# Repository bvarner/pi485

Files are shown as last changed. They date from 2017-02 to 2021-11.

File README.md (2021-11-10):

# Pi485 - UART TTL (Raspberry Pi / Arduino) to RS485
## What is it?
Pi485 lets you connect the RX / TX pins on your Raspberry Pi (/dev/ttyAMA0) or Arduino device to an RS-485 network, 
and transmit / receive as if the network were a normal serial device.

## What can it do?
* Create a low-cost RS-485 network of devices using serial I/O.
* Communicate with other RS-485 networks.

Recent models of HVAC equipment (so called, "communicating" units) typically use RS-485 for the physical connection.
This makes deciphering the comms stream a software problem, and one that many people have already started working on!

## Features
All of the project variations in this repository feature the following:

* Termination Jumper. None of the commercial offerings or existing modules I've seen allow you to disable the termination resistor. On a 
multi-module RS-485 network, it's necessary that middle-nodes not have the termination resistor in the circuit, or the bus signals will 
deteriorate significantly.
* Hardware Latched DE / RE pins on the MAX485 driven by TX activity, with a 'RO' (Read Only) jumper header.
Adding a jumper will force your device to be 'read only' by disabling the hardware latch of the DE / RE Pins.
* Software controlable off / on. Using a GPIO pin (3.3v) you can turn the circuit 'on' or 'off', allowing for a software reset of the 485 
module, pseudo "power management", or simply give you the time to setup your UART tty before initiating a communication connection.
If you prefer the 'always on' approach, you can simply hook up positive voltage to the control pin, and the circuit will always be on.

## What's in this repository?
This repository contains [KiCad EDA](http://kicad.org/) source schematics, PCB layouts, and rendered SVG plots.

The SVG Plots can be used to print your own PCB, or you could try using them as a template for making your own.

## What? Make my own PCB?
I've had good success with the layouts in this repo using the laser-printer hot-iron transfer method. I've gotten excellent results with 
Hammermill Color Laser Gloss (sku 163110) paper. It's a 32lb very smooth gloss paper like you'll find on lightweight magazine covers.
The 163110 takes and transfers toner very well, and is light enough for use in nearly every laser printer I've run across.
When soaked in water for a few minutes after ironing the paper easily peels off without removing the toner. I normally lightly sand the 
left-over transfer with 1500 grit paper to remove the last of the paper fibers and any gloss 'bleed' before chemical etching the board.

Now that I have my method down I could probably tweak the layouts to shrink the trace size (from 1.0 to 0.8 or 0.7) which would help with
some of the 'bleed' I sometimes get when doing the iron transfer.

I also have invested in some inexpensive carbide drill bit sets from 0.3 - 1.2mm for drilling the PCBs in a drill press.

If you're interested in a prebuilt board, contact me (bvarner) via github. I would be willing to coordinate a small run, and I may have a 
few boards on hand (or on ebay) you could convince me to part with.

## Usage
To setup a RaspberryPi so that you can use the UART for what you want rather than it exposing a serial console.

1. Use `raspi-config` to disable the serial console.
2. Enable the UART at boot by editing `/boot/config.txt` and setting `enable_uart=1`.
3. A pi485 requires a logic 'high' signal on the PWR (P1 connector, pin 5) signal line. You can wire up a +3.3v line to force power to always
be 'on', or you can control it with a GPIO pin.

If using a GPIO pin, a convenient way to manage this is to install `wiringpi`, and edit the `/etc/rc.local` script to add the following lines:
```
/usr/bin/gpio mode 1 out
/usr/bin/gpio write 1 1
```

You can also take the opportunity to set your tty settings in `/etc/rc.local` if you so desire.

## Hardware Configurations

### Standalone
This complete solution can be assembled from discrete components. It uses a Max485 IC, and NE555 timer, and some discrete components to 
implement a hardware level RS-485 interface that automatically controls the DE / RE pins based on TX activity, allows for jumper 
configuration of termination, and adds blinken-lights for TX / RX, and Power.

This configuration is the easiest one to fabricate at home. Everything from pad size, to trace width and clearance restrictions have been
tweaked to make this easier to work with for novices. Armed with a single-sided copper clad board, some ferric chloride, a fine-tipped 
sharpie marker and a steady hand, you could build this layout without doing an iron transfer. However, the component cost is higher. The
PDIP Max485 in small quantities is by itself more expensive than a single LC Technologies RS485 module used by the bearer configuration.

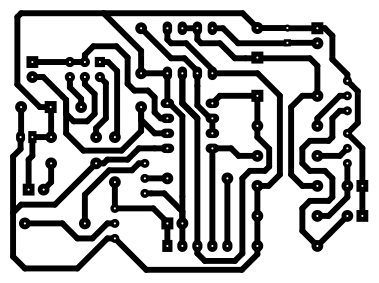
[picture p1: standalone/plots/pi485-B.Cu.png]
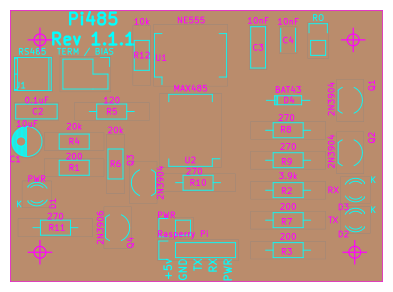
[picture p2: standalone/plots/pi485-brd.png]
 

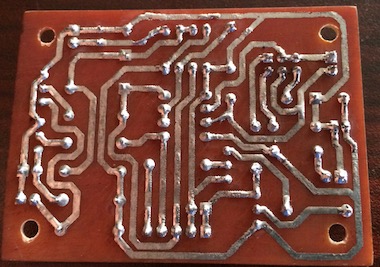
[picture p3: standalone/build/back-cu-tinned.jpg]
Tinned PCB
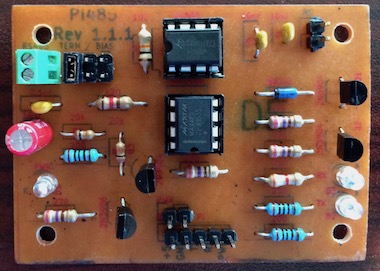
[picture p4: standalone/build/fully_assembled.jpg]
Assembled PCB
 

### Bearer
The bearer board is designed to hold an [LC Tech MAX485 module](http://www.chinalctech.com/index.php?_m=mod_product&_a=view&p_id=811), which
is an inexpensive module based around a max485 in a surface-mount, slew-rate limited configuration. 
These modules include some support components like power filtering capacitors, a power LED, and some pull-up resistors.
Building a bearer board is a bit more tricky, as it has lower clearance tolerances between traces, thinner traces, and requires that you 
modify (unsolder) some resistors off the LC Tech module. However, when full BOM part costs are taken into consideration, if you're making
more than one pi485, it'll be cheaper to use the bearer configuration.

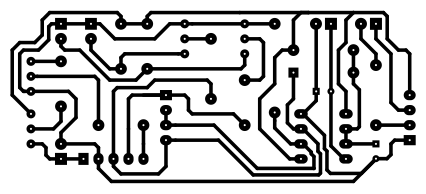
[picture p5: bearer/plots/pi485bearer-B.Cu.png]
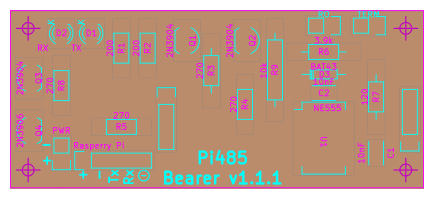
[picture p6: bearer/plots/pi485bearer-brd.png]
 

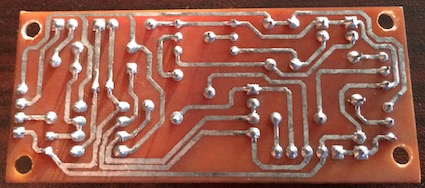
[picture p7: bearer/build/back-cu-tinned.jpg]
Tinned PCB
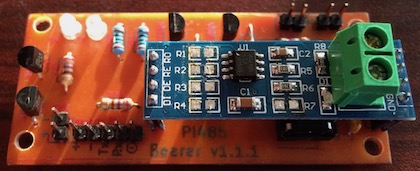
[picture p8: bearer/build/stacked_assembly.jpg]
 

The bearer board adds the 555 latch circuit for DE/RE control from the TX line, RX / TX LEDS, power on/off, and 
jumper termination control from the standalone board design (if you unsolder the 120Ohm resistor on the LC Tech module).

In my experience, if you want to make more than one of these devices, it's much cheaper to purchase the LC Tech modules and build Pi485 
bearer boards to hold them.

## Project Background
I've had a couple Raspberry Pi's laying about my home for a few years now. After running across the 
[Infinitude project](https://github.com/nebulous/infinitude), I realized that my 
HVAC system (a Bryant unit) is actually a 'communicating' system as well. I've had in the back of my mind for some time a project to hook up
a raspberry pi, and track long-term time-series data on my HVAC unit, performance, and temperature differentials.

### Off The Shelf Module Shortcomings / Circuit Analysis / Reasons this project exists.

Almost every module I've looked at is based on the [MAX485](http://datasheets.maximintegrated.com/en/ds/MAX1487-MAX491.pdf).

#### Overly simplistic opinionated view of RS-485.
It seems that off-the-shelf modules tend to approach the MAX485 series of half-duplex (two wire RS485) chips as a pretty simple TTL->485 
converter, suitable for locating at the _endpoints_ of a very simplistic single master-slave network. In order to drop in multiple modules 
(multiple slaves) or enable multi-master communications and form a true network, there's some hardware work that needs to be done (removing
termination resistors) and software control of the RE / DE with a GPIO (which open you up to a whole slew of software timing issues).

#### Soldered on Termination
For example, the LinkSprite module and the LC Tech modules both carry 120Ohm termination resistors, and no jumper header to remove it from
the circuit. The only practical option to add these modules as a network node other than an 'end point' is to unsolder that resistor.

#### Lack of TX / RX Visibility
I like [blinkenlights](https://en.wikipedia.org/wiki/Blinkenlights). These products should have blinkenlights.

#### DE / RE Pin Hysteresis 
Additionally, the LC Tech module has the DE and RE pins of the Max485 directly accessible over headers but provides no extra circuitry to 
drive the input to those pins based off the TTL TX. These two pins of a Max485 are responsible for setting the duplex state of the chip 
(Driver Enable / Receiver Enable) for either sending or receiving data. The RE pin is active on Logic Low (GND) and the DE pin is active on 
Logic High (~20ma of forward voltage). For this reason, you'll commonly see these pins wired together. When set High, the Max485 disables
receiving, and enables transmitting. When pulled low, it enables receiving and disables transmitting. The LC Tech module seems to defy all 
logic and reason in how it wires up the DI, DE, RE, and RO pins. Each pin has a 10k pull-up resistor. So unless you're actively draining 
these pins to ground with your logic circuits,  your max485 is going to end up in "write" mode by _default_. In a multi-master half-duplex
system like an HVAC unit (the initial target application for pi485) this causes a big problem.

I've found many schematics which suggest tying the DE / RE pins to a separate GPIO. This is a terrible idea in practice. In a busy RS485 bus
the time between the DI/DE pins shifting and the start of output on the TX pin would effectively guarantee a collision on the network.

I've also found schematics for RS-232 -> RS-485 converters which work by converting the 232 signal to TTL, then the TTL to RS-485. In these
circuits, they tend to leverage a 555 timer as a time-delayed latch, to hold the DE / RE pins in transmit mode based on the state of the TTL
TX pin. This seems like a really good idea in theory, and in circuit simulations (I don't have a physical scope) it appears that the 555
output will respond quickly enough for at least a 38400baud network to cleanly communicate all the necessary symbols over the wire (given 
the sizing of resistors and capacitors in use with the 555).

In this [555 TTL Latch Simulation](http://tinyurl.com/hx6gfwh), there's a +5V supply, GND, and a H/L logic input (clickable) on the left. 
The output pin of the 555 has a H/L output detector on it, and drives an NPN transistor to turn on an LED. In a real circuit using this 
technique, the 555 output pin would drive the DE/RE pins on a Max485. As an example, checkout the 
[AVT530](http://serwis.avt.pl/manuals/AVT530.pdf), an RS232 to RS485 converter that uses TTL as an intermediary. The schematic is on page 2.

The same company also uses this same 555 & Max485 circuit on their [USB to RS485](http://serwis.avt.pl/manuals/AVT530USB.pdf) converter.

The down-side with these circuits, is that there is a timing differential after the TX pin stops transmitting that the RE pin is held high.
Recall earlier I mentioned things about start / stop bits? This is where that comes into play.
At 38400Hz (as in the simulation above) this delay accounts for an entire clock cycle of bit transmission on the bus. In the interactive 
simulations above, note how if you switch the TTL input high (0 or idle) it takes 2 clocks before the 555 sets the output back low. If your
bit protocol doesn't include a stop bit (idle / high) then the DE / RE will not be disabled at the appropriate time. Without stop bits, you 
will transmit one extra idle (logical 1) on the 485 bus and miss receiving a bit for a clock with these latched circuits.

Here's another [simulation of the 555 latch circuit with pulsed input](http://tinyurl.com/hn6zreu). In this revision, we've added a pull-up
resistor (5k) to the input trigger to hold it 'high' when idle, moved the input clk to drive a decade counter, and tied output pins from the
counter to switch an NPN transistor that sinks the trigger pin low when the counter has a high output. Think of the counter as sending 
logical 1's and 0's by pushing a switch. When the switch (transistor) is closed, the TR voltage drops to ground. If you have start or stop
bits enabled in your stream, this initial drop (0) will be the start bit, which will trigger the 555 output high. In the AVT circuits, this 
drives the RE / DE pins high, putting the MAX485 into transmit mode. An idle 'high' stop bit (Q8) will let the timer's capacitor drain, 
resetting it's output pin. But if you're not using start / stop bits... and you're just getting a stream of bits that is synchronized 
in software, then using a 555 latch is going to be asking for trouble.

In looking at the LinkSprite module, I found it interesting that it dispenses with a time-delay latch and supplies power to the DE / RE pins
via MOSFETS switching a 0.33mA current based upon the TX input. This seems rather 'icky' to me, since logically I would think the DE / RE
pins going 'high' whenever the TTL signal goes idle, would cause an issue. So I threw together a 
[simulation of the TTL input with MOSFET](http://tinyurl.com/glnvxa2) triggers. This confirmed what I thought as far as behavior without 
delay. The good news here, is if you're sending a '0' on the RS-485 bus, you'll transmit that 0, and be prepared to receive any values from
the bus immediately afterward. So if your protocol doesn't use stop bits, you'll be able to read the stream without error. The natural
question at this point is, "what if I'm trying to transmit a '1' (logical TTL high / idle value)?" In that case, the DE pin would be pulled
low, along with the RE pin, putting the MAX485 into Driver disable, Receiver Enabled mode. I'm not sure if this would effectively pulse the
RS-485 bus in an appropriate manner. The Bus signals bits based on bias differences between the two wires, A and B. Something about this
arrangement smells funny.

According to the stuff I've read on RS-485, a driver 'idle' would be A+, B- potentials. After pouring over the Max485 datasheet, I don't see
anything that will lead me to believe RE high / DE low would result in A+, B- potentials being emitted on output lines of the chip.

Nevertheless, it must work... right? Unless the LinkSprite and LC Tech components aren't being tested in multi-master half-duplex 
networks. I have a feeling that's exactly what's going on, since they both carry soldered-on termination resistors that cannot be 
jumper-disabled. That means that if you introduced a network of these devices with more than two nodes, you'd have pretty significant signal
degradation.

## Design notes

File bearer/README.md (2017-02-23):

# Pi485 Bearer Module

Based upon what I learned while creating the Standalone pi485, this board is meant to function as a carrier / bearer for an
[LC Technologies RS485 module](http://www.chinalctech.com/index.php?_m=mod_product&_a=view&p_id=811), adding the RX / TX LEDs,
power controll, and latched DE / RE pin driving to this very inexpensive and commonly available module.

Unlike the standalone board this layout prioritizes compactness over ease of use for beginners.
The trace clearances are tighter and you'll need to remove five surface mount resistors from the RS485 module. In practice, I've found 
these boards are reasonably easy to produce with a laser printer hot iron transfer.

## PCB Layout

Copper Layer Front Layers
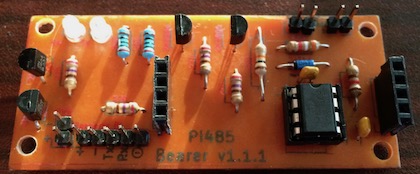
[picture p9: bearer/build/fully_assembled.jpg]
Assembled
Tinned PCB 

is designed to hold these RS485 modules

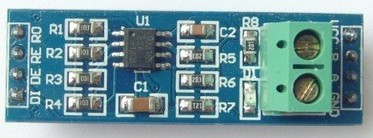
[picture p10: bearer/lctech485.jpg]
LCTech485
 Full Stack

## Schematic
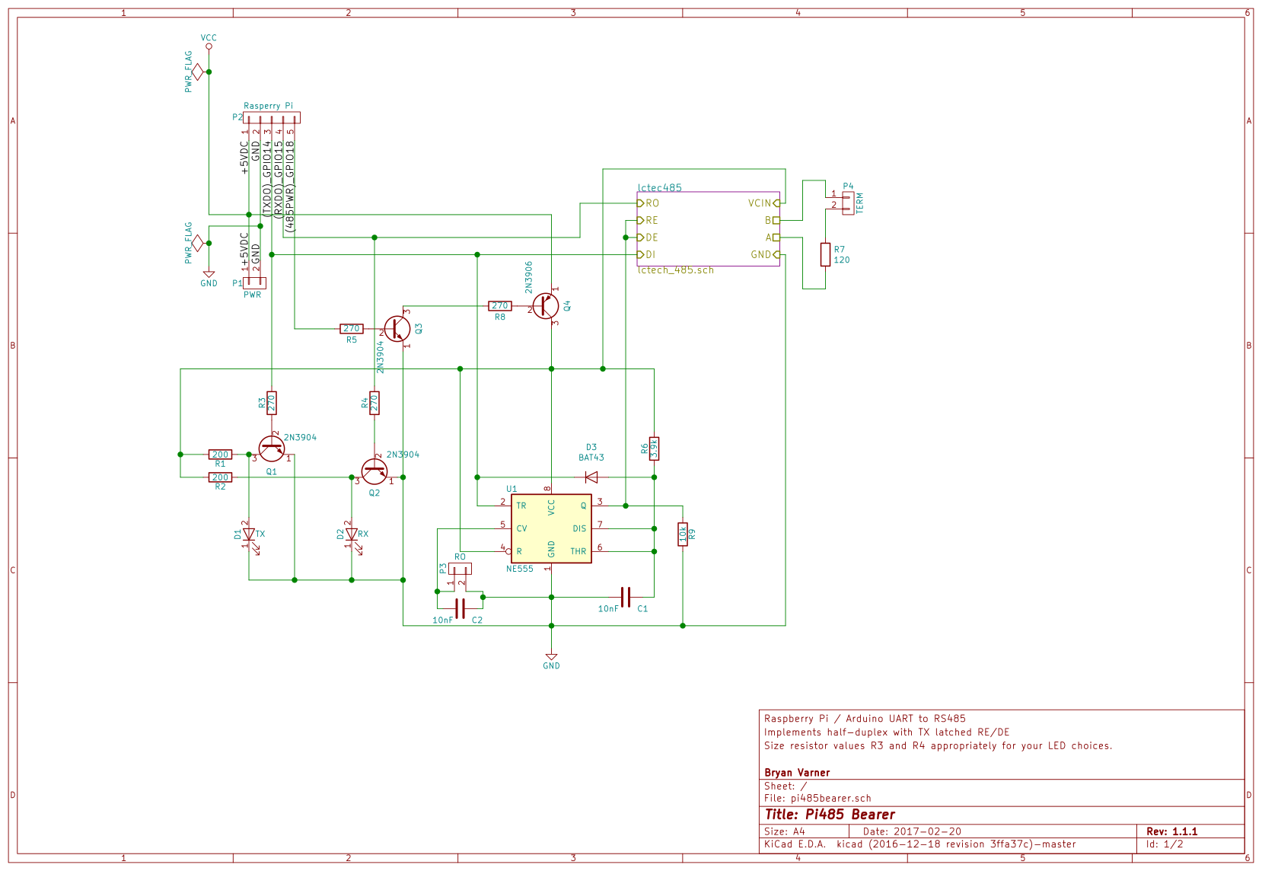
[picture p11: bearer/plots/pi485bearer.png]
Schematic


# Design Goals
* Add the functions and features of the standalone module in a slightly more compact layout that can accomodate inexpensive 485 modules.
* Leverage the RS 485 module due to the module cost being less than the the cost of a discrete terminal block header, max485 IC, power LED, 
LED resistor, and filtering capacitors. These boards do shave a couple USD off the cost of UART based RS-485.
* Latch the DE / RE pins on the Max485 based upon the UART TX activity, but allow that to be disabled (force read-only mode)
* Include jumper termination for the A/B lines of the RS485 bus.

For in-depth details on the function of [the circuit](plots/pi485bearer.png) refer to the [Standalone Module README](../standalone/README.md).

# Build Instructions

1. Start off by customizing the resistor values for your LEDs. I used [http://ledcalc.com/] to help inspire my choices.
2. Use KiCad's PCB editor (pcbnew) to customize any footprint changes.
3. Print the [back copper](plots/pi485bearer-B.Cu.svg) layer on a laser printer, using glossy photo paper.
4. Print the [front](plots/pi485bearer-brd.svg) layers on a laser printer, using glossy photo paper.
5. Cut your board (62mm x 30mm)
6. Transfer the copper printout using a hot iron and some water.... (youtube reference coming). Touchup with a resist pen if necessary.
7. Etch the board.
8. Clean the board.
9. Tin the board.
10. Reflow the board (bake it in an oven).
11. Drill the component holes.
12. Place & solder components.
13. Assemble!
14. Remove the 120Ohm resistor (R7), and the 4 10kOhm pull-up resistors (R1 - R4) from the LC Tech 485 Module.
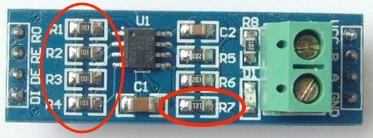
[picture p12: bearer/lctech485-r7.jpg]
R7 Has to Go


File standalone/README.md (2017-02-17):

# Pi485 Standalone Module

This is a stand-alone module for RS-485 communication, utilizing a MAX485 IC and a NE555 Timer IC.
The PCB for this project is the most 'simple' of the two to etch yourself. Most of the pads are 
oversized, the copper traces are significantly wider and spaced far enough that it's possible 
to create a PCB with a resist marker by hand. 

## PCB Layout
Copper Layer Front Layers

## Assembled
Back Cu Tinned Populated

## Schematic
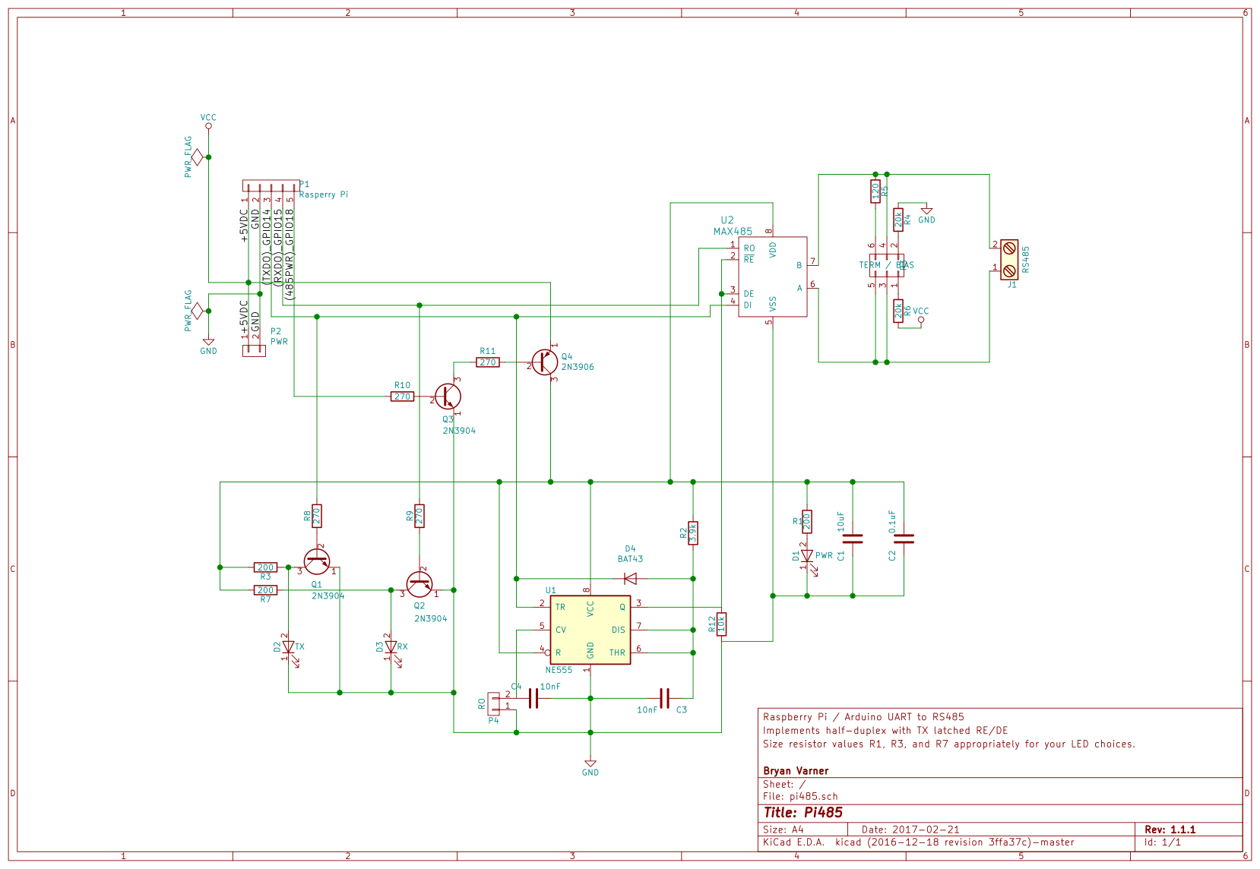
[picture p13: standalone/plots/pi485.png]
Schematic


# Design Goals
* [Simple / Easy To Understand Circuit](plots/pi485.png)
* Easily fabricated at home with simple tooling
* Reasonably inexpensive to source parts for and build (~$20 or less)
* Latch the DE / RE pins on the Max485 based upon the UART TX activity, but allow that to be disabled (force read-only mode)
* Include jumper termination for the A/B lines of the RS485 bus.

To achieve these goals the PCB layout in this repository is a single-side clad board, components on the front, copper on the back.
The traces are large (0.4mm!), the pads are oversized where possible, and I've allowed plenty of clearance between traces and pads, making
it possible to touch-up a hot-iron transfer with an ink-resist pen. You may even be able to draw the existing tracks with a pen free-hand.

For tooling, you'll need the 'standard' PCB etching supplies; a bottle of Ferric Chloride, some isopropyl alcohol, gloves, 
a dish to do the etching, and an appropriately sized drill bit. (I had a 0.040" bit in a set) I'd recommend you have a drill press, too.

I highly recommend doing a hot-iron transfer of laser printer toner. Print the SVGs using a laser printer onto glossy photo (or magazine)
paper. Heat the board with an iron, then stick the printout to the board. Press the printout firmly to the board using the hot iron (you're
goal is to melt the toner to the board surface), and then start soaking with water and continue steaming. Firm pressure and heat will do a
good job of sticking the printout onto the board. It works surprisingly well. Once you've steamed the paper (or soaked it in water) and it
starts to fall of the board, you can touchup any trace or pad issues with a resist pen, and etch the board.

I also use a kitchen oven to bake the board once it's tinned. Getting it up to ~425 degrees F does a nice job of reflowing the solder,
which makes it much easier to drill the holes.

# Circuit Analysis / Explanation

## TTL Serial Communication Basics
TTL signaling of serial data idles 'high'. When data is being transmitted on the TX pin, it first drops 'low' (a start bit), 
transmits it's data, and then sends a stop bit. In TTL, a logical 0 is GND. A Logical 1 is +V. But when there are no transmissions taking 
place, the pin holds 'high', at +V. I personally found [this SparkFun tutorial](https://www.sparkfun.com/tutorials/215) to be highly 
educational on the nuances of TTL. If your protocol doesn't include a start / stop bit, this can be problematic for converting TTL 
_transmissions_ to RS-485.

## Schematic Breakdown
The [current schematic](plots/pi485.png) is fairly straightforward.

All of the resistor values connected directly to LEDs should be double-checked for your LED selections.

## Power Input / Signal Connections
Starting in the upper left quadrant of the schematic, you have the input header pins (P1). There's a second pair of headers for an additional
+5vdc and ground connections (P2). I use the second two-pin header to connect my power supply, then connect the other pins to the Pi providing
power to the RaspberryPi and connecting the UART pins and 485PWR signal line.

## RX / TX LED Signaling
The RX & TX lines are tapped with 270ohm resistors to pull the 5vdc down to an appropriate level for tripping the NPN transistors in the 
lower left side of the schematic. When the voltage on the RX / TX pins goes LOW (signaling data, not idle), the NPN halts the flow of 
electricity from the Collector to the Emitter (opens the switch), leaving the only path to ground being through the LEDs. Make sure you 
size your R3 and R7 resistors appropriately for your LEDs. The NPN transistors in this circuit are specced as 2N3904's, but 2N4401s will 
work just as well.

## Power Filtering & Power LED 
Above the RX / TX LED section, there's a small block with two transistors (an NPN and a PNP) working together to create a 'high-side' power
switch for the entire circuit. The PNP transistor switches the +5v supply for the rest of the circuit, based on the on/off state of the 
NPN. Using the NPN to control the PNP allows us to drive the 5v line with a 3.3v GPIO, and to do it in a '1' is on, '0' is off, semantic.

If you'd rather the circuit always be 'on', omit these components, or connect pin 5 on the P1 header to the 5V or a 3.3V line.

Looking to the lower-right portion of the schematic, you'll find several decoupling filter capacitors and a power LED.

## UART TX Connections
The TX line is connected to the trigger pin of a 555 timer, and then to the Data Input pin of the Max485.

The 555 timer circuit is a slightly modified missing pulse detector, which you'll find right smack in the middle of the schematic.

When the TX power drops below the threshold defined by the 3.9k resistor (R2), the output of the 555 goes HIGH. After a very short delay,
(it switches ~38400hz) the output will go back low, unless the the TX line input is still low. In a typical missing pulse detector, the 555
output will go back low regardless of the TX line (555 trigger) input. The addition of the shottky diode changes this configuration, and 
holds the output steady so long as the input is steady. The diode has to be capable of switching reverse voltage bias fast enough to keep
the input lower than the threshold / discharge output, but without affecting the input signal line. Hence the use of the BAT43, rather than
a 'normal' silicon diode.

The output of the 555 timer is used to set the input on the DE / RE (Driver Enable / Receiver Enable) pins on the max485. When HIGH, the 
Driver Enable is set, putting the Max485 into 'master' mode and broadcasting on the 485 bus. When LOW, the RE pin (which has inverted logic
on a Max485) is enabled, putting the Max485 into 'receive' mode.

If there is a jumper present on the CTRL pin (5) of the 555 timer, the 555 output will always be 'LOW' effectively holding the Max485 in 
Receive mode forever.

## UART RX Connection
Moving along the RX line, it's connected to the Data Output pin of the Max485.

## Max485 Output
The output pins of the Max485 are configured to setup a high-resistance reference against the current 'ground', and to allow the termination
(120 Ohm) resistor to be removed from the circuit.

## Putting it all together...
The circuit provides basic decoupling / power filtering, some passive LED monitoring of RX / TX lines, and a latch-based DE / RE driver 
logic for the Max485, along with a basic resistance network to setup the A/B differentials on the RS-485 bus.

# Analysis of other products / options
I am not a professional EE. In reality I'm a software engineer who got into this out of curiosity. I have always detested 
black-boxes (things which I cannot take apart or understand completely) and it's my nature to dismantle, analyze, evaluate, and eventually 
take that knowlege and apply it to things I synthesize. I consider electronics a 'hobby'. My comments here are my own personal opinions
and are not an endorsement or meant to dissuade or persuade your purchasing decisions.

# Build Instructions

1. Start off by customizing the resistor values for your LEDs. I used [http://ledcalc.com/] to help inspire my choices.
2. Use KiCad's PCB editor (pcbnew) to customize any footprint changes.
3. Print the [back copper](plots/pi485-B.Cu.svg) layer on a laser printer, using glossy paper.
4. Print the [front](plots/pi485-brd.svg) layers on a laser printer, using glossy paper.
5. Cut your board to size (63mm x 46mm)
6. Transfer the copper printout using a hot iron and some water.... (youtube reference coming). Touchup with a resist pen if necessary.
7. Etch the board.
8. Clean the board.
9. Tin the board.
10. Reflow the board (bake it in an oven).
11. Drill the component holes.
12. Place & solder components.
13. Clean up, and enjoy!

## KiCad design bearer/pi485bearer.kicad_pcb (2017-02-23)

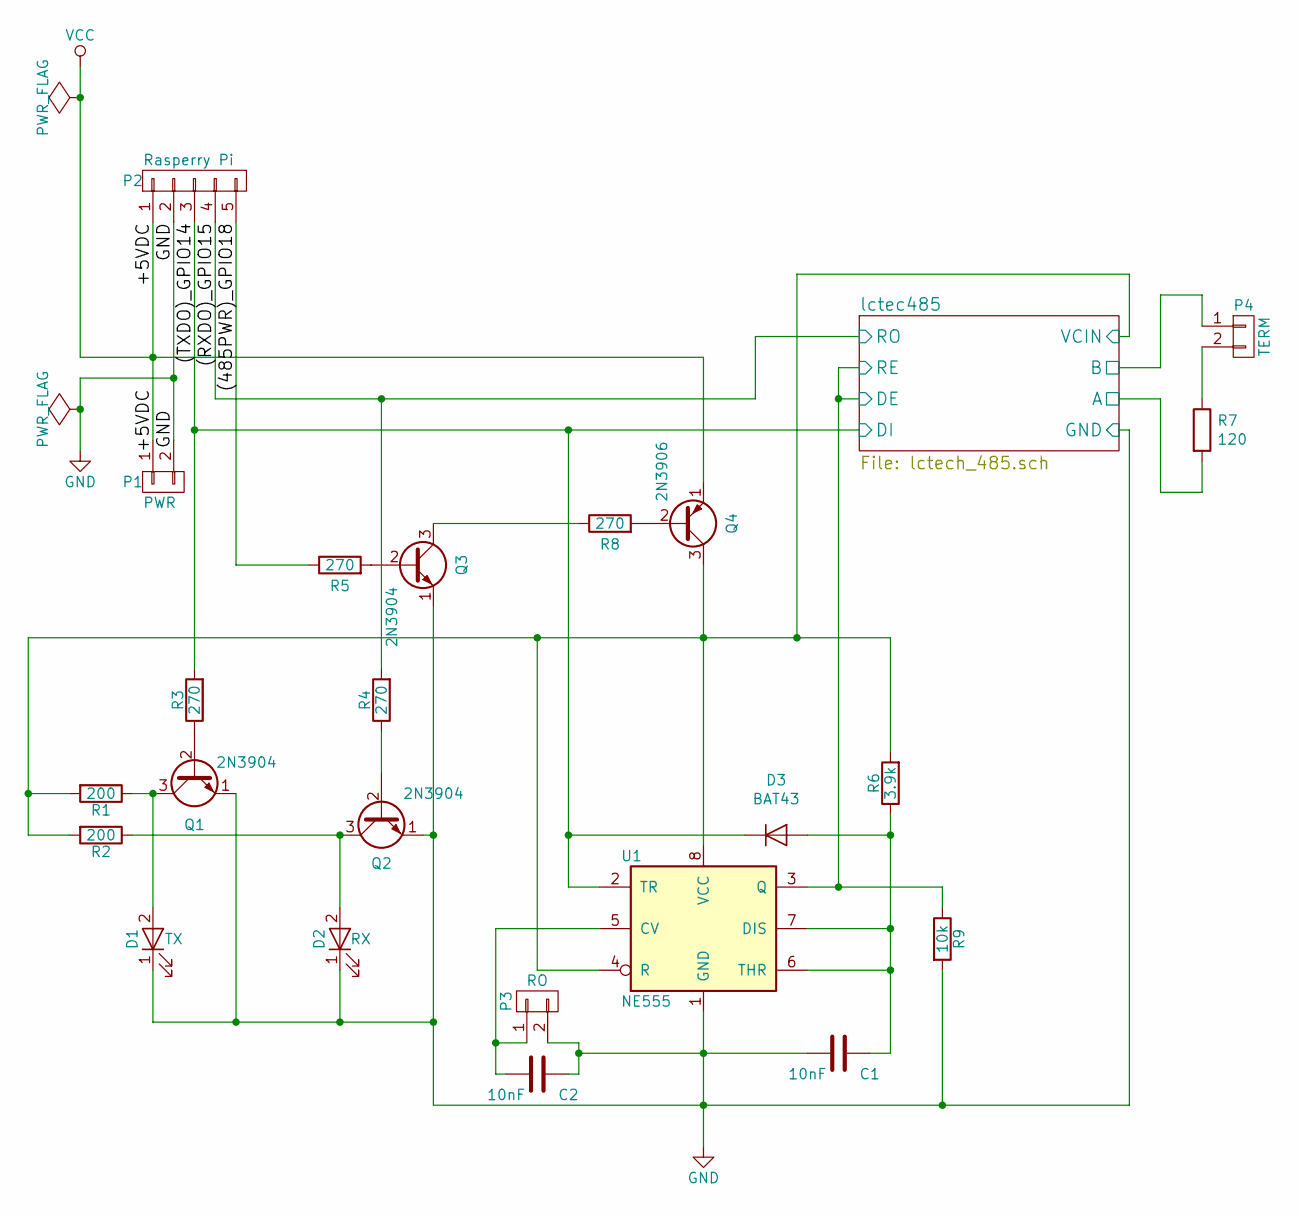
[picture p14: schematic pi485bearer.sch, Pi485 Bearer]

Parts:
C1, C2: 10nF; C_Rect_L4_W2.5_P2.5
D1: TX; LED-3MM
D2: RX; LED-3MM
D3: BAT43; Diode_DO-35_SOD27_Horizontal_RM10
P1: PWR; Pin_Header_Straight_1x02
P2: Rasperry Pi; Pin_Header_Straight_1x05
P3: RO; Pin_Header_Straight_1x02
P4: TERM; Pin_Header_Straight_1x02
Q1, Q2, Q3: 2N3904; TO-92_Inline_Wide
Q4: 2N3906; TO-92_Inline_Wide
R1, R2: 200; Resistor_Horizontal_RM7mm
R3: 270; Resistor_Horizontal_RM10mm
R4, R5, R8: 270; Resistor_Horizontal_RM7mm
R6: 3.9k; Resistor_Horizontal_RM10mm
R7: 120; Resistor_Horizontal_RM10mm
R9: 10k; Resistor_Horizontal_RM15mm
U1: NE555; DIP-8_W7.62mm_LongPads

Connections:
/(485PWR)_GPIO18: P2.5, R5.1
/(RXDO)_GPIO15: P2.4, R4.2; also elsewhere on the board
/(TXDO)_GPIO14: D3.1 (K), P2.3, R3.2, U1.2 (TR); also elsewhere on the board
/lctec485/A: R7.2; also elsewhere on the board
/lctec485/B: P4.1; also elsewhere on the board
/lctec485/DE: R9.1, U1.3 (Q); also elsewhere on the board
/lctec485/VCIN: Q4.3 (C), R1.2, R2.2, R6.2, U1.4 (R), U1.8 (VCC); also elsewhere on the board
GND: C1.2, C2.1, D1.1 (K), D2.1 (K), P1.2, P2.2, P3.2, Q1.1 (E), Q2.1 (E), Q3.1 (E), R9.2, U1.1 (GND); also elsewhere on the board
unnamed: C1.1, D3.2 (A), R6.1, U1.6 (THR), U1.7 (DIS)
unnamed: C2.2, P3.1, U1.5 (CV)
unnamed: D1.2 (A), Q1.3 (C), R1.1
unnamed: D2.2 (A), Q2.3 (C), R2.1
unnamed: P4.2, R7.1
unnamed: Q1.2 (B), R3.1
unnamed: Q2.2 (B), R4.1
unnamed: Q3.2 (B), R5.2
unnamed: Q3.3 (C), R8.1
unnamed: Q4.2 (B), R8.2
VCC: P1.1, P2.1, Q4.1 (E)

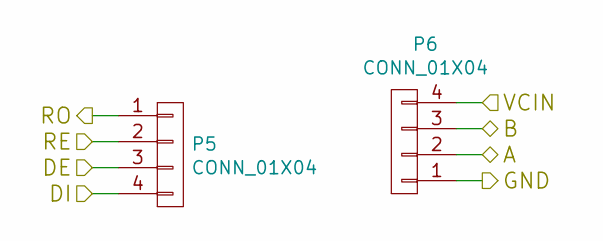
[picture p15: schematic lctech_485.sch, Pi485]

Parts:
P5, P6: CONN_01X04; Socket_Strip_Straight_1x04

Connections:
/(RXDO)_GPIO15: P5.1; also elsewhere on the board
/(TXDO)_GPIO14: P5.4; also elsewhere on the board
/lctec485/A: P6.2; also elsewhere on the board
/lctec485/B: P6.3; also elsewhere on the board
/lctec485/DE: P5.2, P5.3; also elsewhere on the board
/lctec485/VCIN: P6.4; also elsewhere on the board
GND: P6.1; also elsewhere on the board

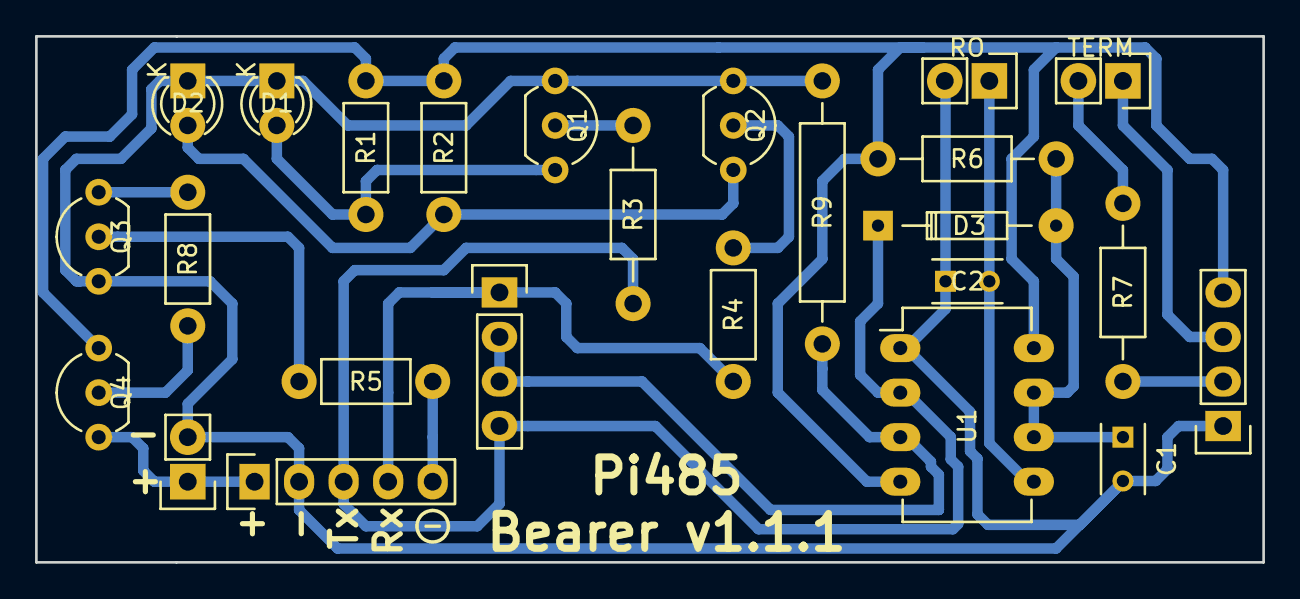
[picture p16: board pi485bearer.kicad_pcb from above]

Board: 2 copper layers, 70.0 x 30.0 mm, 25 parts (0 on the bottom side), 19 nets.

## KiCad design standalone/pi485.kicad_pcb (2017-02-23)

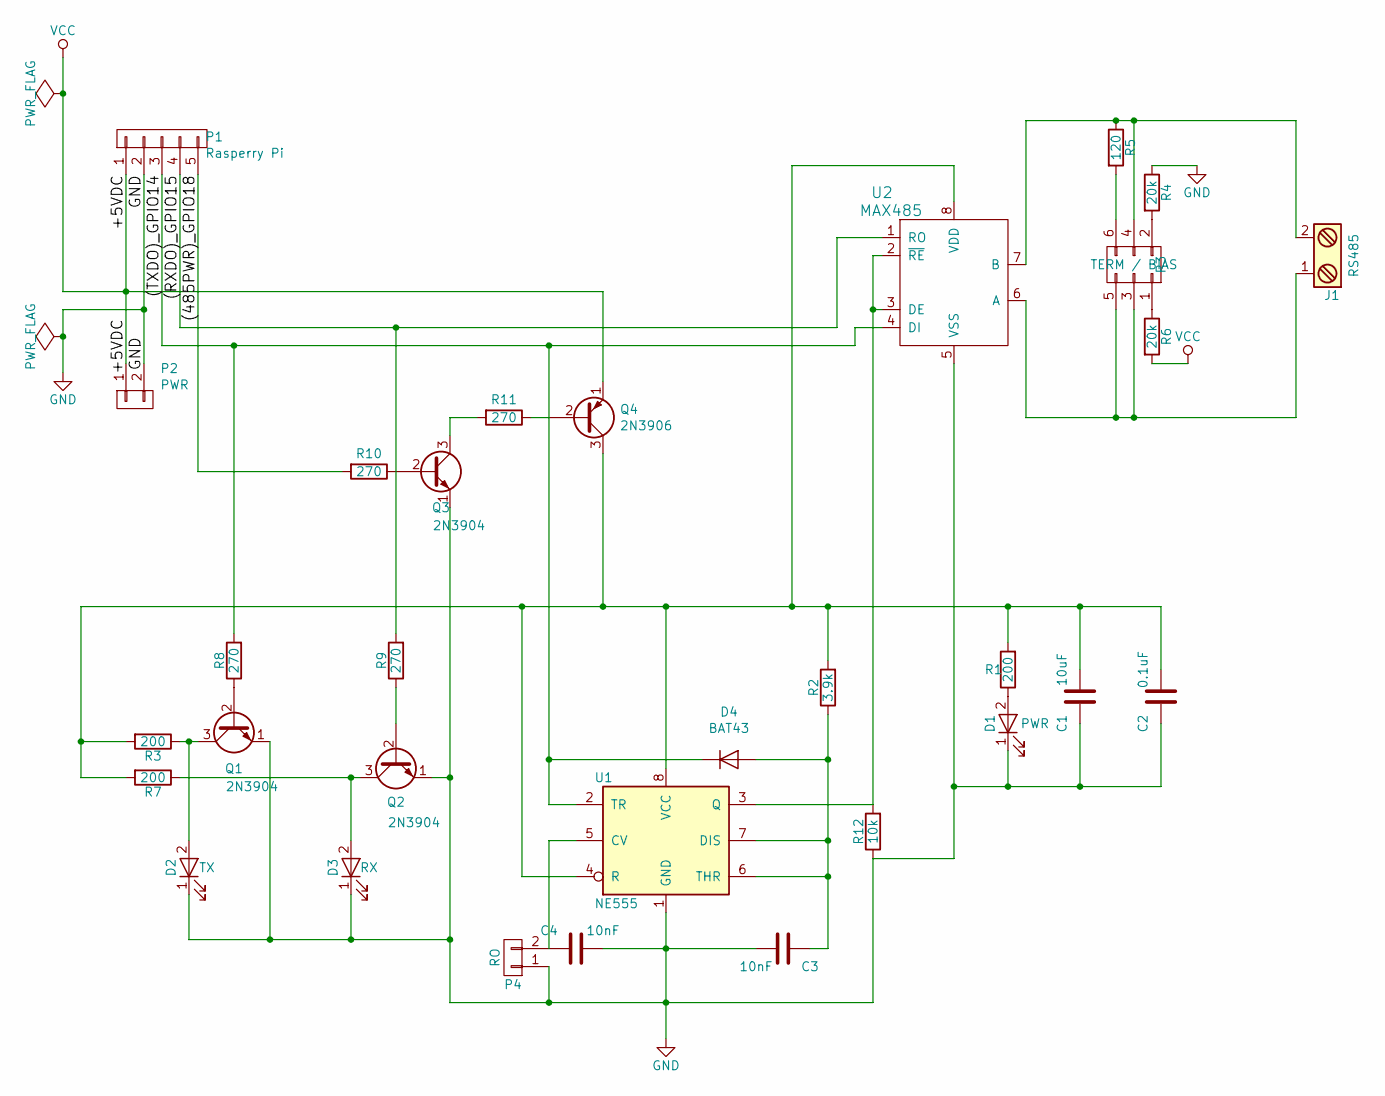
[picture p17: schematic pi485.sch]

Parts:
C1: 10uF; C_Radial_D5_L11_P2
C2: 0.1uF; C_Rect_L7_W2.5_P5
C3: 10nF; C_Rect_L7_W2.5_P5
C4: 10nF; C_Rect_L4_W2.5_P2.5
D1: PWR; LED-3MM
D2: TX; LED-3MM
D3: RX; LED-3MM
D4: BAT43; Diode_DO-35_SOD27_Horizontal_RM10
J1: RS485; TerminalBlock_Pheonix_MPT-2.54mm_2pol
P1: Rasperry Pi; Pin_Header_Straight_1x05
P2: PWR; Pin_Header_Straight_1x02
P3: TERM / BIAS; Pin_Header_Straight_2x03
P4: RO; Pin_Header_Straight_1x02
Q1, Q2, Q3: 2N3904; TO-92_Inline_Wide
Q4: 2N3906; TO-92_Inline_Wide
R1: 200; Resistor_Horizontal_RM7mm
R2: 3.9k; Resistor_Horizontal_RM10mm
R3, R7: 200; Resistor_Horizontal_RM10mm
R4, R6: 20k; Resistor_Horizontal_RM7mm
R5: 120; Resistor_Horizontal_RM10mm
R8, R9, R10, R11: 270; Resistor_Horizontal_RM10mm
R12: 10k; Resistor_Horizontal_RM7mm
U1: NE555; DIP-8_W7.62mm_LongPads
U2: MAX485; DIP-8_W7.62mm_LongPads

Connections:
/(485PWR)_GPIO18: P1.5, R10.2
/(RXDO)_GPIO15: P1.4, R9.2, U2.1 (RO)
/(TXDO)_GPIO14: D4.1 (K), P1.3, R8.2, U1.2 (TR), U2.4 (DI)
GND: C1.1, C2.1, C3.2, C4.2, D1.1 (K), D2.1 (K), D3.1 (K), P1.2, P2.2, P4.1, Q1.1 (E), Q2.1 (E), Q3.1 (E), R4.1, R12.1, U1.1 (GND), U2.5 (VSS)
unnamed: C1.2, C2.2, Q4.3 (C), R1.2, R2.2, R3.2, R7.2, U1.4 (R), U1.8 (VCC), U2.8 (VDD)
unnamed: C3.1, D4.2 (A), R2.1, U1.6 (THR), U1.7 (DIS)
unnamed: C4.1, P4.2, U1.5 (CV)
unnamed: D1.2 (A), R1.1
unnamed: D2.2 (A), Q1.3 (C), R3.1
unnamed: D3.2 (A), Q2.3 (C), R7.1
unnamed: J1.1, P3.3, P3.5, U2.6 (A)
unnamed: J1.2, P3.4, R5.1, U2.7 (B)
unnamed: P3.1, R6.1
unnamed: P3.2, R4.2
unnamed: P3.6, R5.2
unnamed: Q1.2 (B), R8.1
unnamed: Q2.2 (B), R9.1
unnamed: Q3.2 (B), R10.1
unnamed: Q3.3 (C), R11.2
unnamed: Q4.2 (B), R11.1
unnamed: R12.2, U1.3 (Q), U2.2 (~RE), U2.3 (DE)
VCC: P1.1, P2.1, Q4.1 (E), R6.2

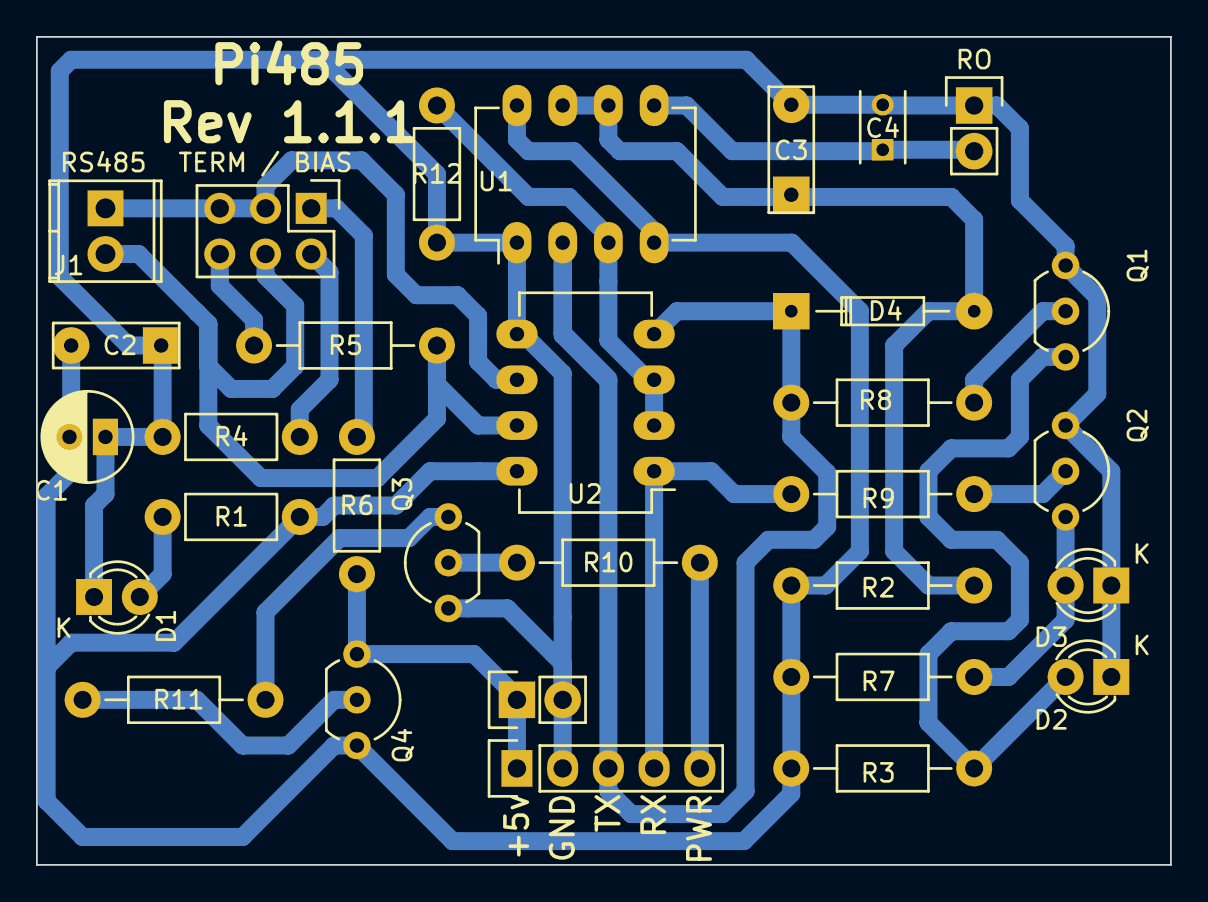
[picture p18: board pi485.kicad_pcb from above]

Board: 2 copper layers, 63.0 x 46.0 mm, 31 parts (0 on the bottom side), 22 nets.

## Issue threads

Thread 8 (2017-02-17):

Transmitting data leaves the DE/RE latch stuck.

bvarner, 2017-02-17:
A lack of a ground connection on the 555 CV pin seems to be leaving the latch 'stuck', even with the reset pin pulled forever high.

When shorting this out to ground (R/O jumper) it of course seems to 'work'.

Connecting another 10nf cap across the R/O jumper may be a "quick n' dirty fix", but I haven't had much luck with that yet, although early tests were promising.

It probably time to setup a small arduino & Raspberrypi test bed for making sure this stuff works before I push to 'master'. :-(

I'm also somewhat concerned about the bonding of DE / RE pins, and if that should be jumpered as well (do we expect to see what we write -- ala local echo in hardware) or are we just supposed to be blasting stuff away? How do we know?

I'm testing with [Infinitive](https://github.com/acd/Infinitive) on a raspberry pi at the moment, and the TX issues are clearly present there.

On the bright side, we're certainly reading from the 485 bus appropriately...

bvarner, 2017-02-20:
10nf cap doesn't change behavior, so the 'power smoothing' effect on the voltage comparator doesn't seem to change much. Drat. The CV should have the cap, based on the specs of the 555 I'm using, so I missed that.

But the latch being stuck high just doesn't make any sense. it ought to be coming back down to gnd, unless it's getting stuck high and just doesn't have anywhere for the stuff to dissipate, or something. If there's some sort of capacitance on the re / de pins, this could explain things.

bvarner, 2017-02-20:
This is somewhat embarrassing, but....

After adding a 10k pull-down resistor (I had a bunch of them laying around) and the 10nf filter cap to the CV line of the 555, the issue still persisted.

I finally started to wonder if my threshold was just not being crossed. Taking some measurements with the voltmeter showed that I was overdriving my 5v line (supply was putting out 5.5v, VCIN traces were measuring at 5.45v).  This, with the 3.9k resistor was putting our thresholds out of range of the 3v TX TTL logic on the trigger. (ha!)

Reducing the power supply to ~4.98v, along with the pull down and 10nf filter seems to work perfectly.

bvarner, 2017-02-21:
The 'development' branch is now up to date with a fix for this issue.

However, until I get a couple 1.1.1 boards assembled and tested (and update the photos) I'm going to leave this 'open'.

Closed 2017-02-23.

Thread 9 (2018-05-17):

Driver

dryansweet, 2018-05-17:
Is there a RasPi driver for this scheme you're using? I'm unable to get the the direction pin working well at the user level.

bvarner, 2018-05-17:
With this hardware there is no need for software flow control (setting the direction pins) from user-level. You hook up the power and the TX/RX pins to the raspberry pi UART, and off you go.

This is precisely why I implemented flow control in hardware.

My rambling analysis includes complaints about hysteresis in software flow control schemes.
https://github.com/bvarner/pi485#de--re-pin-hysteresis.

For what it's worth, if you search for "UART to RS485 Converter RS485 to TTL Module Precise Module" you'll find some plain circuit board modules on aliexpress and amazon which work _great_ and are far more robust (proper termination, protection, etc.) than my very simplistic schematics here. They also implement hardware flow control.

I've actually switched over to using those. The pi485 stuff was an excellent educational project for myself, though. ;-)

Good luck!

Closed 2018-05-17.

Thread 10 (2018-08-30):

3.3V Logic

ongun-kanat, 2018-08-30:
Can this design work with 3.3V logic but 5V power?

bvarner, 2018-08-31:
In theory, it should!

You may need to adjust R8 and R9 to a lower value to supply enough current to the transistors that switch the signal LEDs on / off, but that should be it.

The BAT43 should still saturate around 3.3v, and the current applied to the trigger on the 555 should be sufficient.

If you give it a shot, I'd love to know!

bvarner, 2018-08-31:
I poked around with the simulation I made of the timer circuit, and after switching the input clock to 3.3v, the timer side of things still triggers.

From what I've found on the max485 chips, 3.3v should be enough to drive the input pins. Just watch out for what voltage comes off the output pin -- it may be vcc. Your best bet would be an opto-isolator.

I'm pretty sure these really inexpensive boards have a lot more protection circuitry:
https://www.aliexpress.com/premium/RS485-TTL.html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

Things you probably should have -- like fuses, etc.
I even broke down and started using one, after having my own board hooked up for quite a few months.

Closed 2018-08-31.

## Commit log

2017-01-09 initial add of discrete version
    [pi485.dsn, pi485.kicad_pcb, pi485.sch]
2017-01-11 Initial checkin of current work. This stuff does not work
    [pi485.dsn, pi485.kicad_pcb, pi485.sch]
2017-01-12 Made a bunch of changes...
    New board size (70mm x 53mm) single layer, better layout.
    Replace silicon diode with saturated NPN, added NPN tirggered TX / RX LEDs.
    [pi485.dsn, pi485.kicad_pcb, pi485.sch]
2017-01-12 Removed dimensions.
    [pi485.kicad_pcb]
2017-01-12 Original plot exports
    [pi485.kicad_pcb]
2017-01-12 Updated layer selection
    [pi485.kicad_pcb]
2017-01-13 Switched A/B output on the RS485 screw terminal for pin 1 to be A, pin 2 to be B.
    [pi485.kicad_pcb, pi485.sch]
2017-01-13 Forgot to bump the PCB.
    [pi485.kicad_pcb]
2017-01-13 Resistor / LED adjustments, BAT43 restoration (digi-key order placed). Footprint updates.
    [pi485.kicad_pcb, pi485.sch]
2017-01-13 Updated the PCB, tweaked some routes and pad sizes.
    [pi485.kicad_pcb]
2017-01-13 Some tweaks
    [pi485.kicad_pcb]
2017-01-17 * Rotated board 90 degrees. * Major update to footprints. Resistors are 10mm, LEDs are 3mm. * Manually re-routed / cleaned up traces & positiiong of quite a few things. * This could be pulled so much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
    [pi485.kicad_pcb, pi485.sch]
2017-01-17 Oh yeah, the date.
    [pi485.kicad_pcb]
2017-01-17 I think I must be getting tired
2017-01-17 Added SVGs. Replotted the front of the board.
2017-01-18 Fixed the footprint issues with the 2N4401 transistors being 'backwards'
    [pi485.kicad_pcb, pi485.sch]
2017-01-18 Board #0!
    I built a board tonight. It worked perfectly.
2017-01-18 Adding some photos of board #0
2017-01-18 1.1.0 bump. Added 3.3v control pin to turn on power to the 485 and the PWR LED.
    [pi485.kicad_pcb, pi485.sch]
2017-01-18 VCC control of the 555. Using a GPIO pin, we can reduce overall power consumption by turning things off when we don't need them.
    [pi485.kicad_pcb, pi485.sch]
2017-01-19 * Added 3.3v enable / disable pin. Can be tied to 3.3v output on the pi, or a GPIO pin to force power off / on of the pi485 circuits. * Enables software control of a RS485 'reset', and will make it e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
    [pi485.kicad_pcb, pi485.sch]
2017-01-19 Hey look, mounting holes.
    [pi485.kicad_pcb]
2017-01-20 Made a carrier board for lc-tech with the 555 trigger, and gpio-controlled power.
    [lctech_485.sch, pi485.dsn, pi485.kicad_pcb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]
2017-01-24 Carrier updates.
    [pi485carrier.kicad_pcb]
2017-01-30 Renaming carrier to bearer...
    [lctech_485.sch, pi485carrier.kicad_pcb, pi485carrier.sch]
2017-02-07 Cleaning up intermediary files.
    [pi485.dsn]
2017-02-07 Renamed bearer.
    [lctech_485.sch, pi485.sch, pi485bearer.kicad_pcb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]
2017-02-07 Updating With rendered SVG plots
    [pi485bearer.kicad_pcb]
2017-02-07 Readme for Bearer board.
2017-02-07 Removing photos of first board
2017-02-07 Fixed link, added schematic.
2017-02-07 Replot using small drill marks.
    [pi485bearer.kicad_pcb]
2017-02-07 Updated export plots.
    [pi485.kicad_pcb]
2017-02-07 Rendering boards better.
    [pi485bearer.kicad_pcb]
2017-02-07 Updated Plots
    [pi485.kicad_pcb]
2017-02-07 Include the PCB plots on the main README
2017-02-07 Increased trace thickness
    [pi485bearer.kicad_pcb]
2017-02-07 Updated bearer traces
    [pi485bearer.kicad_pcb]
2017-02-07 Updated bearer with mount holes
    [pi485bearer.kicad_pcb]
2017-02-07 Updated bearer with mount holes... and updated PNGs
2017-02-07 Trace revisions....
    [pi485bearer.kicad_pcb]
2017-02-07 kicad link, some minor wording, now that I've updated the bearer layout.
2017-02-08 Esthetics on the standalone board.
    [pi485.kicad_pcb]
2017-02-08 Symmetry is beautiful.
    [pi485.kicad_pcb]
2017-02-08 Updates and what-not for asthetics.
    [pi485bearer.kicad_pcb]
2017-02-08 Updates for drill marks and bearer rendering
    [pi485bearer.kicad_pcb]
2017-02-08 Some additional cleanup and re-routing
    [pi485.kicad_pcb, pi485bearer.kicad_pcb]
2017-02-09 Updated with TERM / RO values in schemas and PCBs
    [pi485.sch, pi485bearer.sch]
2017-02-10 Low-side NPN switching. We'll see if things 'floating' causes issues... if so, I'll have to order a few PNP's to use for high-side switching.
    [lctech_485.sch, pi485.kicad_pcb, pi485.sch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]
2017-02-12 Updated standalone for asthetics.
    [pi485.kicad_pcb]
2017-02-12 standalone reconfigured for high-side PNP switching
    [pi485.kicad_pcb, pi485.sch]
2017-02-12 high-side PNP power switching for the bearer.
    [pi485bearer.kicad_pcb, pi485bearer.sch]
2017-02-12 Esthetics and what-not...
    [pi485.kicad_pcb, pi485.sch, pi485bearer.kicad_pcb]
2017-02-13 Moved the P1 P2 connectors to make a bit more sense, enlarged the bearer to 70mm, four mount holes per board.
    [pi485bearer.kicad_pcb]
2017-02-14 Removed an unnecessary junction.
    [pi485.sch]
2017-02-16 * Found a huge issue with the bearer... where the TX and RX were backwards, due to the header for the module being ... um... reversed. :-/
    [pi485bearer.kicad_pcb]
2017-02-16 * Re-placed & routed the bearer, now with the headers in the proper orientation. *facepalm*
    [pi485bearer.kicad_pcb]
2017-02-17 Increased trace size, clearance for PCB etching / printability.
    [pi485bearer.kicad_pcb]
2017-02-20 1.1.1 schematics, trace plots, etc.
    [lctech_485.sch, pi485.kicad_pcb, pi485.sch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]
2017-02-21 This was caused by over-volting the supply, which caused the voltage divider for the 555 to put the 3.0v from the TX idle out of range of resetting the 555. Hah!
2017-02-21 Updates for jumpered biasing on standalone boards. The silly bearer modules you can just unsolder the biasing resistors if it becomes an issue. I should probably add jumpering for that too, but at th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
    [pi485.kicad_pcb, pi485.sch, pi485bearer.kicad_pcb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]
2021-11-09 Update README.md
    https://forum.kicad.info/t/warning-avoid-all-links-to-kicad-pcb-org-use-kicad-org/31521
